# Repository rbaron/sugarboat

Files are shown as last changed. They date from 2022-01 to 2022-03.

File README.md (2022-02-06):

<p align="center" style="background-color: white; padding: 10px">
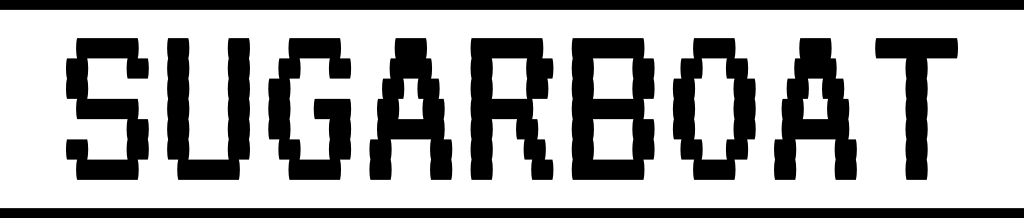
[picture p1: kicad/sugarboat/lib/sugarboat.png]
sugarboat logo
	
<p>

A digital [hydrometer](https://en.wikipedia.org/wiki/Hydrometer). The main use case is measuring the amount of sugar in liquids during the process of beer and wine making.

# How does it work?
Sugarboat floats on top of the liquid being measured. Because of its shifted center of mass, it will float at an angle. This *tilt angle* (see image below) is larger for denser liquids and smaller for less dense liquids. We can then estimate the density of a solution from this angle.

<p align="center">
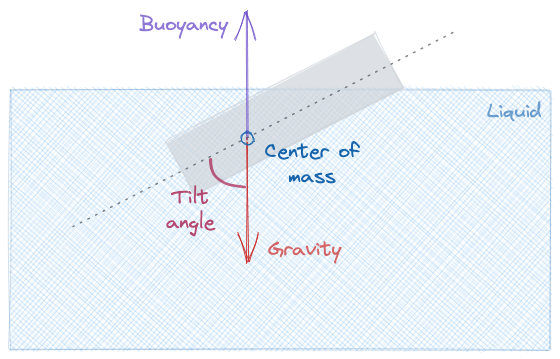
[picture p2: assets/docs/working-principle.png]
	
<p>

As is usual in the beer and wine making processes, we can additionally correlate the estimated density of a solution with the amount of sugar present in it.

The estimated [density](https://en.wikipedia.org/wiki/Relative_density) and [sugar content](https://en.wikipedia.org/wiki/Brix) are exposed - along with the temperature, relative humidity, current battery voltage and more - through [Bluetooth Low Energy (BLE)](https://en.wikipedia.org/wiki/Bluetooth_Low_Energy) services. This repository contains examples of how to read these values under [`clients/`](./clients).

# Tech specs
* [nRF52840](https://www.nordicsemi.com/Products/nRF52840) system-on-a-chip
  * Reads sensors, estimates the sugar content and exposes their values via [Bluetooth Low Energy (BLE)](https://en.wikipedia.org/wiki/Bluetooth_Low_Energy) services
* [SHT30](https://www.mouser.com/datasheet/2/682/Sensirion_Humidity_Sensors_SHT3x_Datasheet_digital-971521.pdf) temperature & humidity sensor
* [MPU6050](https://invensense.tdk.com/products/motion-tracking/6-axis/mpu-6050/) accelerometer + gyroscope estimates the tilt angle
* Li-Ion 18650 battery
  * Battery life of over a year on a single charge
  * Built-in [TP4056](http://www.tp4056.com/d/tp4056.pdf)-based charging circuit
* USB-C for battery charging and programming
  * [UF2 support](https://learn.adafruit.com/adafruit-feather-m0-express-designed-for-circuit-python-circuitpython/uf2-bootloader-details) using a [forked Adafruit_nRF52_Bootloader](https://github.com/rbaron/Adafruit_nRF52_Bootloader) allows for direct programming via the USB-C port. This bootloader needs to be flashed to the blank nRF52 chip once using a J-Link or compatible SWD programmer

# Waterproof enclosure
A [preform PET tube (or "petling")](https://en.wikipedia.org/wiki/Polyethylene_terephthalate#Bottle_processing_equipment) is used to enclose the electronics and provide sugarboat with the buoyancy it needs. The printed circuit board is designed to fit tightly into a tube with the inner diameter of around 33 mm and inner height of 123 mm. The board is slightly wider than 33 mm - some light sanding needs to be done to ensure a nice, snuggly fit. I bought my containers from [this eBay offering](https://www.ebay.com/itm/132379354446).

# Repository organization
| Directory | Description |
|---|---|
| [`kicad/`](./kicad) | Electronics - schematic, PCB layout, bill of materials and fabrication files |
| [`code/`](./code) | Firmware - a [PlatformIO](https://platformio.org/) project using the Arduino framework |
| [`clients/web/`](./clients/web) | A web interface for calibrating, configuring and reading sugarboat's sensors |
| [`clients/arduino/`](./clients/arduino) | A barebones Arduino sketch showing how to read sugarboat's tilt angle, temperature & battery voltage using a Bluetooth Low Energy client |
| [`clients/esphome/`](./clients/esphome) | An [ESPHome](https://esphome.io/) client that integrates with [Home Assistant](https://www.home-assistant.io/) |

# Web client
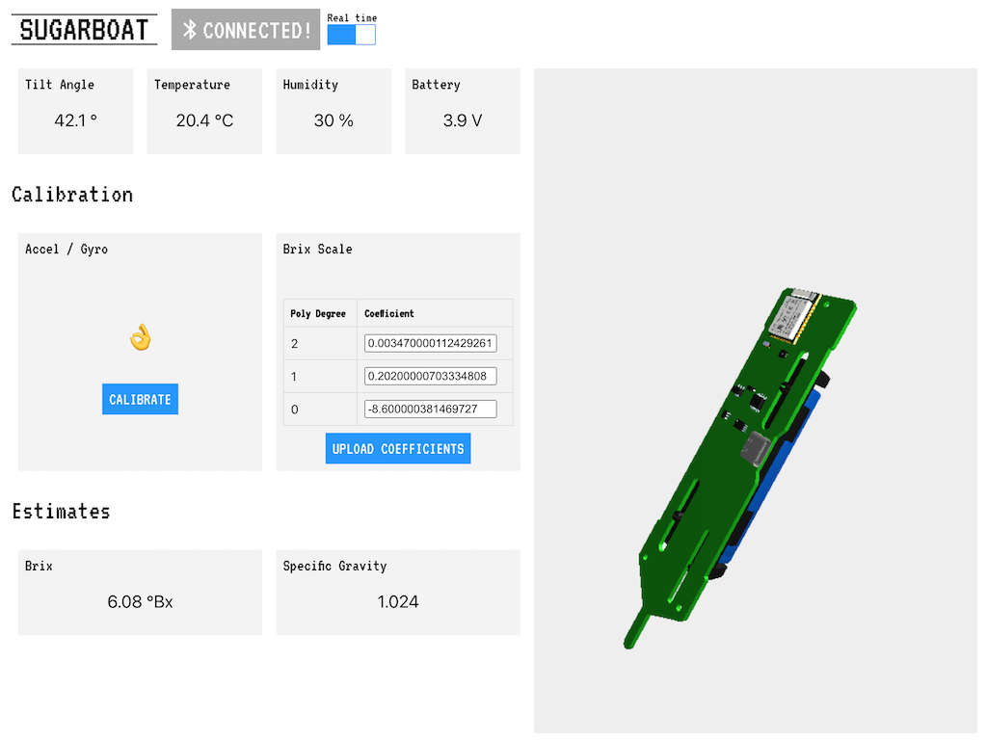
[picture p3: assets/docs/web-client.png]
web client screenshot

This client is a web page that connects to sugarboat using the [Web Bluetooth API](https://developer.mozilla.org/en-US/docs/Web/API/Web_Bluetooth_API). It lets you calibrate, configure and read the sensor values right from your web browser, wirelessly.

The web client's source code is in [`clients/web/`](./clients/web).

# Calibration
TODO.

# Bootloader flashing
To support programming via the built-in USB-C port (via [UF2](https://github.com/microsoft/uf2)), sugarboat requires a bootloader to be flashed to the chip. This is a one-time operation.

I have [forked the Adafruit nRF52 Bootloader](https://github.com/rbaron/Adafruit_nRF52_Bootloader) and added support to sugarboat. To build and flash the bootloader:

```bash
$ git clone git@github.com:rbaron/Adafruit_nRF52_Bootloader.git
$ cd Adafruit_nRF52_Bootloader/
$ make BOARD=sugarboat all
$ make BOARD=sugarboat erase
# Look for the build target that contains the merged bootloader + Nordic's SoftDevice and flash it.
# It will be something like _build/build-sugarboat/sugarboat_bootloader-X.X.X-XXX-XXXXXXXXX_s140_6.1.1.hex:
$ nrfjprog --program _build/build-sugarboat/sugarboat_bootloader-0.4.0-149-g5ffac2e_s140_6.1.1.hex -f nrf52 --reset
```

Note that you will need a SWD programmer to complete this operation. A good choice for hobbyists is a [J-Link EDU Mini](https://www.adafruit.com/product/3571). If you buy one, consider getting it from Adafruit.

# License
[CC BY-NC-ND 4.0](https://creativecommons.org/licenses/by-nc-nd/4.0/).

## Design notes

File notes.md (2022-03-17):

# MPU-6050
* [Datasheet](https://invensense.tdk.com/wp-content/uploads/2015/02/MPU-6000-Datasheet1.pdf)
* [Register map](https://invensense.tdk.com/wp-content/uploads/2015/02/MPU-6000-Register-Map1.pdf)
* It's a 6 degrees of freedom IMU
  * Accelerometer with 3 axes => Reads
  * Gyroscope with 3 axes
* But also has a built-in "MotionFusion" Digital Motion Processor (DMP)
  * "Offloads computation of motion processing algorithms" from the host processor (?)
  * Generates "sensor fusion data" (?)
  * So it becomes a 9-axis sensor
  * Somehow lets us extract the orientation from the accelerometer + gyro
  * Apparently [not publicly documented](https://github.com/jrowberg/i2cdevlib/blob/master/Arduino/MPU6050/MPU6050.h#L731)
  * [This GitHub comment](https://github.com/jrowberg/i2cdevlib/issues/528#issuecomment-611634501) links to a PDF containing the specs of the firmware that powers the DMP
  * [Clear explanation of the DMP](https://github.com/jrowberg/i2cdevlib/issues/190#issuecomment-144270345) by the author of i2cdevlibA
  * [Motion determination patent](https://patents.google.com/patent/US20120323520A1/en)

## Articles
* [Geek Mom Projects - DMP data from i2cdevlib](http://www.geekmomprojects.com/mpu-6050-dmp-data-from-i2cdevlib/)
* [The MPU6050 Explained](https://mjwhite8119.github.io/Robots/mpu6050)
  * Awesome resource for calibrating and getting the orientation using the DMP feature. It uses the i2cdevlib linked below

## Code
* [i2cdevlib](https://github.com/jrowberg/i2cdevlib)
  * [Code for reading the DMP](https://github.com/jrowberg/i2cdevlib/blob/master/Arduino/MPU6050/MPU6050_6Axis_MotionApps20.cpp#L118)
    * Apparently makes use of undocumented functionality!
    * There are multiple versions of the
  * [examples/MPU6050-DMP6](https://github.com/jrowberg/i2cdevlib/tree/master/Arduino/MPU6050/examples/MPU6050_DMP6)
    * Computes orientation using the DMP feature
  * [examples/IMU_Zero](https://github.com/jrowberg/i2cdevlib/tree/master/Arduino/MPU6050/examples/IMU_Zero)
    * Calibrates the gyroscope and accelerometer offsets
  * [Issues with PlatoformIO](https://community.platformio.org/t/i2cdev-incompatible-with-teensy-i2c-t3/11537/4)
* [MPU6050_light](https://github.com/rfetick/MPU6050_light)
  * A library for the MPU-6050 that estimates the angles in software (no DMP?)
* [MPU605-tockn](https://github.com/tockn/MPU6050_tockn)
  * Also calculates angles in software

 ## Calibration
 ```
 [-1743,-1742] --> [-7,11]  [719,720] --> [-7,5]    [1101,1101] --> [16381,16386]   [100,101] --> [0,3]     [60,61] --> [0,4]       [1,1] --> [0,1]

 [-1743,-1742]
 [719,720]
 [1101,1101]
 [100,101]
 [60,61]
 [1,1]
 ```

 ## How to calculate the tilt?
 Tilt: the angle between the sensor and the original's frame Z axis (or equivalently the gravity)

 The sensor gives us a quaternion.

### Euler angles
* [Converting quaternions to Euler angles](https://en.wikipedia.org/wiki/Conversion_between_quaternions_and_Euler_angles)
*

### Row pitch yaw

## Alternative approach
* [Inclination sensing with accelerometer](https://www.digikey.com/en/articles/using-an-accelerometer-for-inclination-sensing) article from DigiKey
* [LIS2DW](https://www.st.com/resource/en/datasheet/lis2dw.pdf) ultra low power accelerometer

# Container
* [Centrifuge tube](https://www.thermofisher.com/order/catalog/product/339650)
* [Falcon tube](https://www.fishersci.com/shop/products/falcon-50ml-conical-centrifuge-tubes-2/p-193321)

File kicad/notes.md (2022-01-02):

# Battery Protection
* [DW01a](https://datasheet.lcsc.com/lcsc/1912111437_PUOLOP-DW01A_C351410.pdf) requires two external N-channel MOSFETs
  * [2n7002dw](https://datasheet.lcsc.com/lcsc/2008111605_Yangzhou-Yangjie-Elec-Tech-2N7002DW_C699281.pdf)
  * [fs8205a](https://datasheet.lcsc.com/lcsc/2105241639_TECH-PUBLIC-FS8205A_C2830320.pdf)
    * Two drains are connected

* Reverse polarity protection
  * How would it work when the battery has to charge & also discharge at different times?

# LDO
* [ap2112](https://www.diodes.com/assets/Datasheets/AP2112.pdf)
  * 600 mA
  * 55 uA quiescent current
* [ht7733a](https://www.electroschematics.com/wp-content/uploads/2013/05/ht7750a-ht7727a-ht7730a-ht7733a-datasheet.pdf)
  *
* [ht7333](https://www.endrich.com/fm/2/HT73xx-1v100.pdf)
  * 250 mA
  * 2.5 uA quiescent current

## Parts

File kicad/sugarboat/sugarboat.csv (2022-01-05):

Comment | Designator | Footprint | LCSC
Battery_Cell | BT1 | lib:BAT_1042_modified
0.1u | C1,C10,C11 | Capacitor_SMD:C_0402_1005Metric | C1525
2.2n | C12 | Capacitor_SMD:C_0402_1005Metric | C1531
10u | C2,C3,C4,C5 | Capacitor_SMD:C_0402_1005Metric | C15525
12p | C6,C7 | Capacitor_SMD:C_0402_1005Metric | C1547
100n | C8 | Capacitor_SMD:C_0402_1005Metric | C1525
10n | C9 | Capacitor_SMD:C_0402_1005Metric | C15195
GREEN | D1 | LED_SMD:LED_0402_1005Metric | C409787
RED | D2,D4 | LED_SMD:LED_0402_1005Metric | C130719
B5819W SL | D3 | SOD3716X135N | C8598
DW01A | IC1 | SOT23-6 | C351410
TYPE-C-31-M-12 | J1 | HRO_TYPE-C-31-M-12 | C165948
FS8205A | Q1 | SOP65P640X120-8N
AO3401A | Q2 | Package_TO_SOT_SMD:SOT-23 | C332107
100 | R1 | Resistor_SMD:R_0402_1005Metric | C25076
1k | R2,R4,R5,R11 | Resistor_SMD:R_0402_1005Metric | C11702
2k | R3 | Resistor_SMD:R_0402_1005Metric | C4109
10k | R6,R12,R13 | Resistor_SMD:R_0402_1005Metric | C25744
470k | R7,R8 | Resistor_SMD:R_0402_1005Metric | C25790
5.1k | R9,R10 | Resistor_SMD:R_0402_1005Metric | C25905
TestPoint | TP1,TP2,TP3,TP4,TP5 | TestPoint:TestPoint_Pad_D1.5mm
TP4056 | U1 | SOP127P600X175-9N | C382139
MPU-6050 | U2 | Sensor_Motion:InvenSense_QFN-24_4x4mm_P0.5mm | C24112
HT7330 | U3 | lib:SOT89 | C347190
E73-2G4M08S1C | U4 | lib:E73-2G4M08S1C-modified | C356849
SHT30-DIS | U5 | Sensor_Humidity:Sensirion_DFN-8-1EP_2.5x2.5mm_P0.5mm_EP1.1x1.7mm | C2687423
32.768 kHz | Y1 | XTAL_NX3215SA-32.768K-STD-MUA-14 | C32346

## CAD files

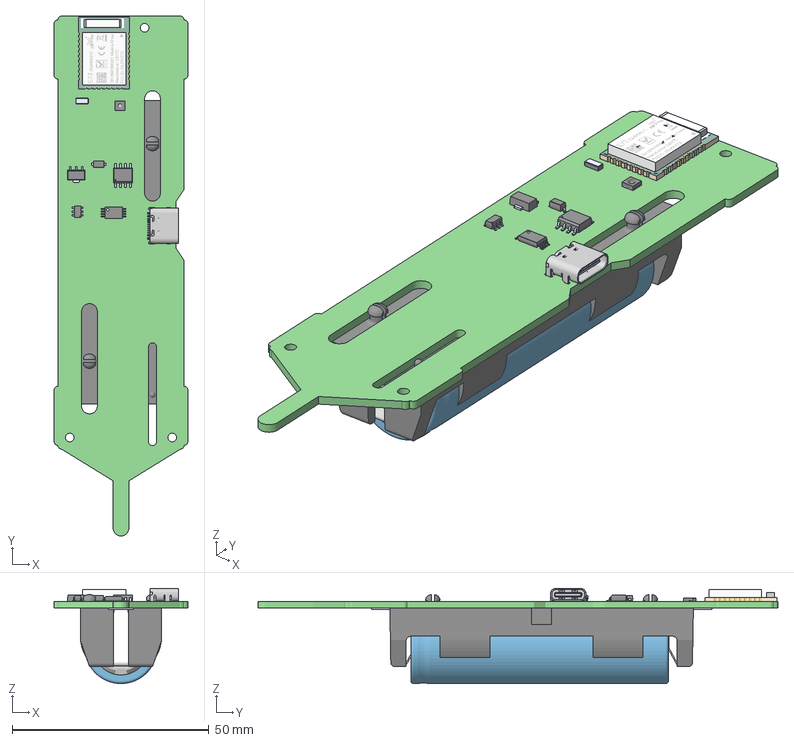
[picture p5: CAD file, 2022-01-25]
clients/web/public/sugarboat.3mf
34.0 x 132.0 x 24.2 mm

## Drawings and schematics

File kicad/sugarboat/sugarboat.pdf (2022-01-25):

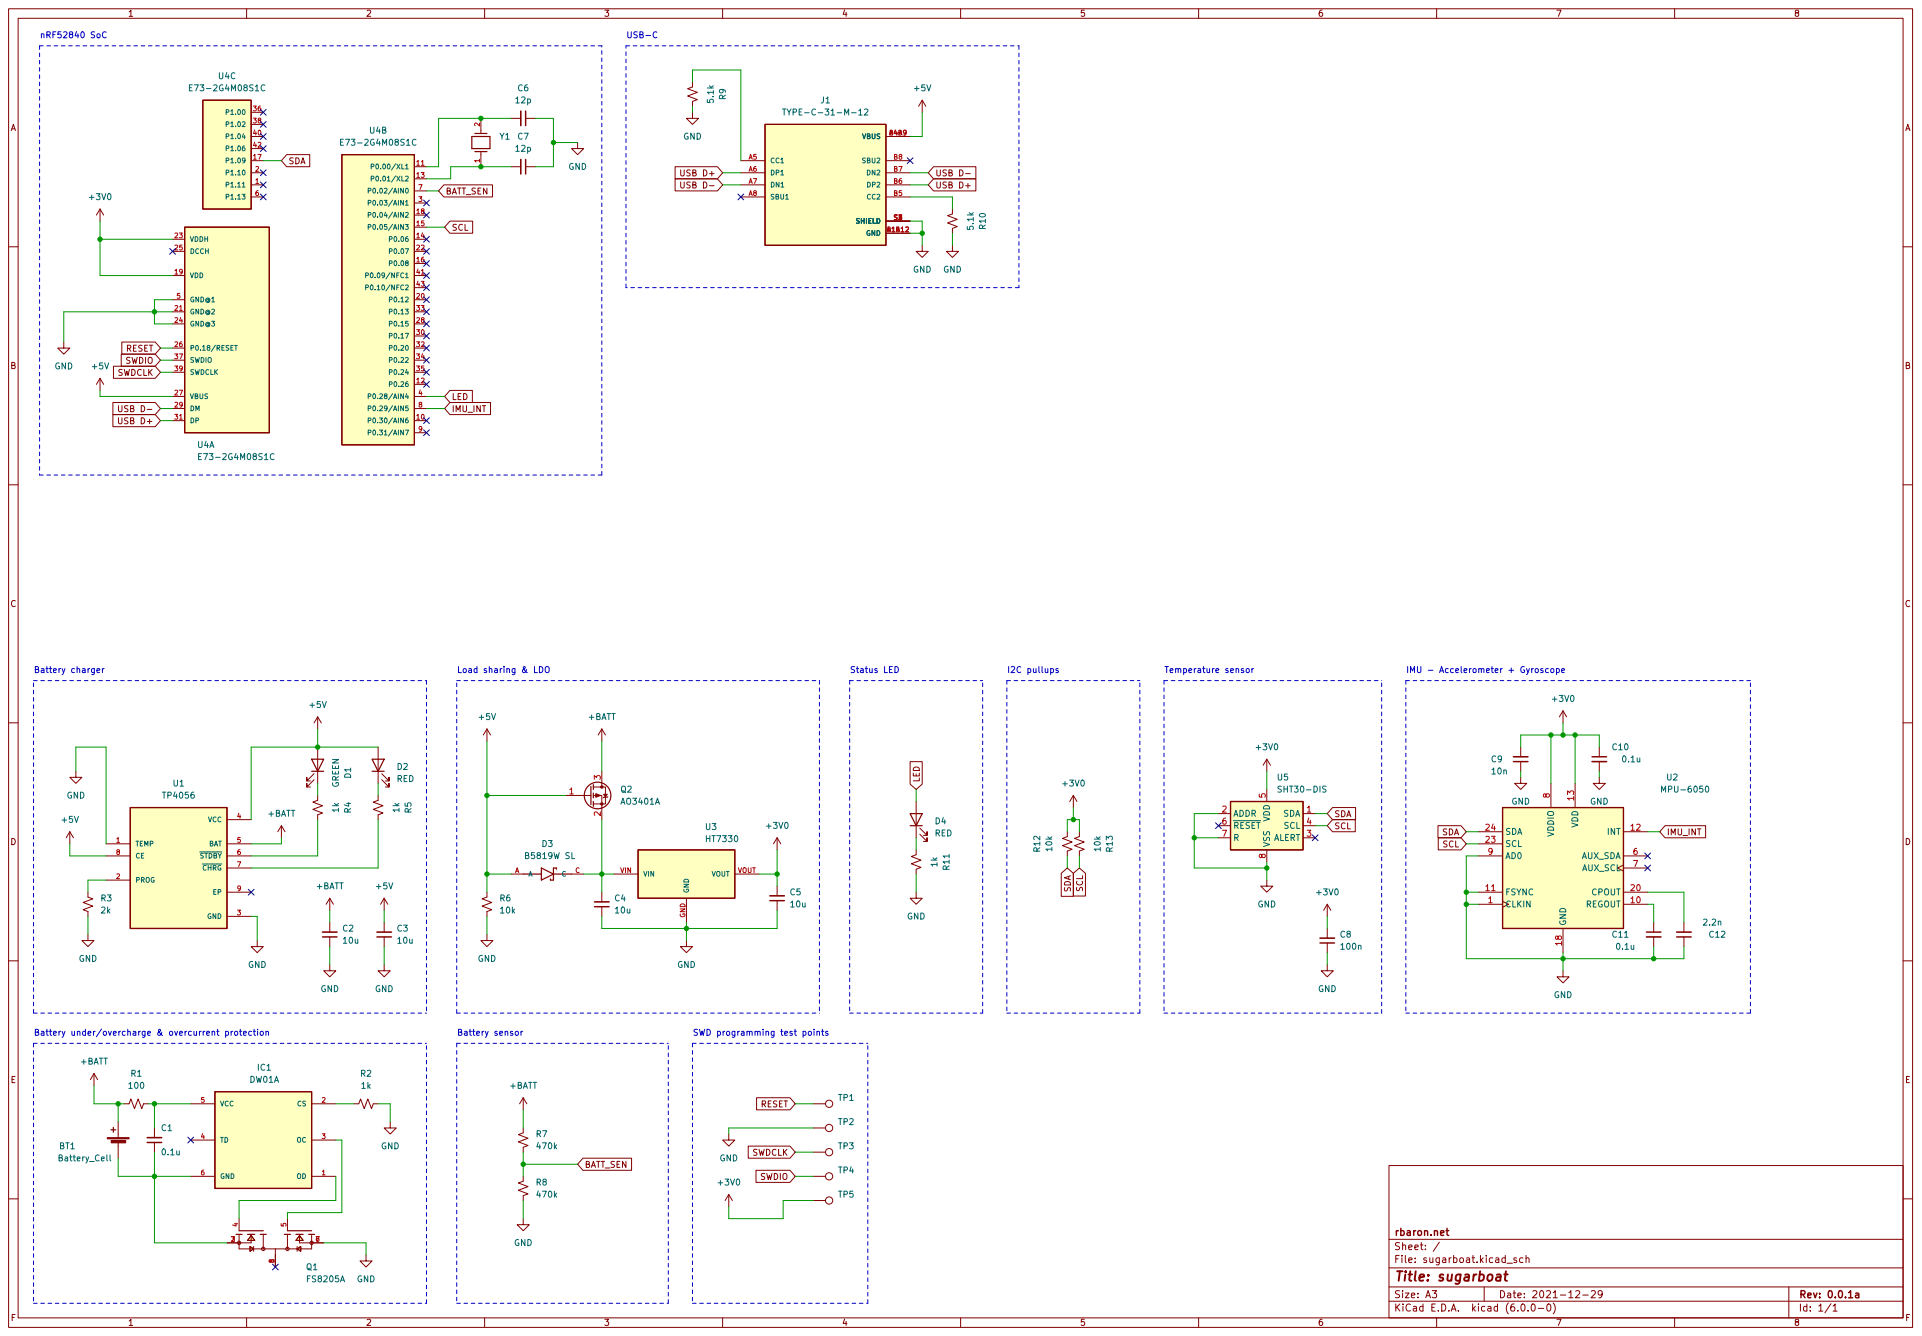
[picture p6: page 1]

Battery under/overcharge & overcurrent protection

SWD programming test points

File: sugarboat.kicad_sch Sheet: / rbaron.net

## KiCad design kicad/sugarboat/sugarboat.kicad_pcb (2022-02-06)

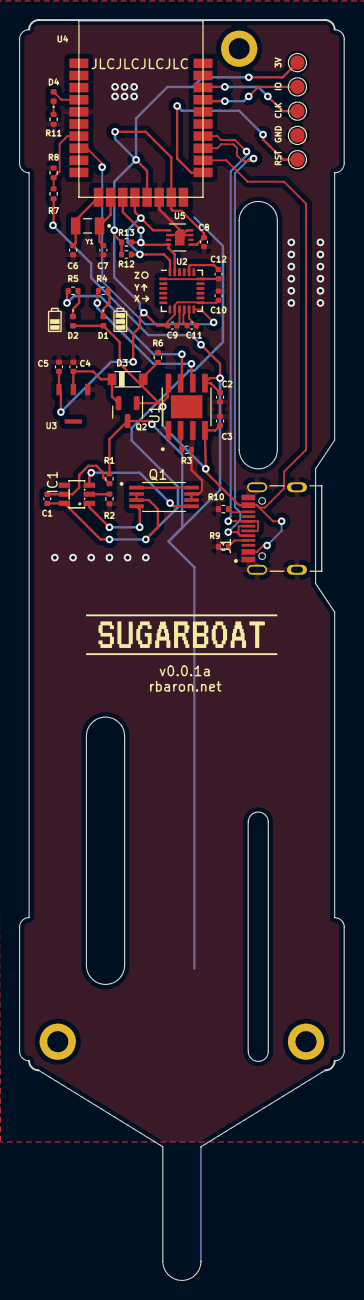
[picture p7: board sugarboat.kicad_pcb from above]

Board: 2 copper layers, 34.0 x 132.0 mm, 45 parts (1 on the bottom side), 32 nets.

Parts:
BT1: Battery_Cell; BAT_1042_modified
C1, C10, C11: 0.1u; C_0402_1005Metric
C2, C3, C4, C5: 10u; C_0402_1005Metric
C6, C7: 12p; C_0402_1005Metric
C8: 100n; C_0402_1005Metric
C9: 10n; C_0402_1005Metric
C12: 2.2n; C_0402_1005Metric
D1: GREEN; LED_0402_1005Metric
D2, D4: RED; LED_0402_1005Metric
D3: B5819W SL; SOD3716X135N
IC1: DW01A; SOT23-6
J1: TYPE-C-31-M-12; HRO_TYPE-C-31-M-12
Q1: FS8205A; SOP65P640X120-8N
Q2: AO3401A; SOT-23
R1: 100; R_0402_1005Metric
R2, R4, R5, R11: 1k; R_0402_1005Metric
R3: 2k; R_0402_1005Metric
R6, R12, R13: 10k; R_0402_1005Metric
R7, R8: 470k; R_0402_1005Metric
R9, R10: 5.1k; R_0402_1005Metric
TP1, TP2, TP3, TP4, TP5: TestPoint; TestPoint_Pad_D1.5mm
U1: TP4056; SOP127P600X175-9N
U2: MPU-6050; InvenSense_QFN-24_4x4mm_P0.5mm
U3: HT7330; SOT89
U4: E73-2G4M08S1C; E73-2G4M08S1C-modified
U5: SHT30-DIS; Sensirion_DFN-8-1EP_2.5x2.5mm_P0.5mm_EP1.1x1.7mm
Y1: 32.768 kHz; XTAL_NX3215SA-32.768K-STD-MUA-14

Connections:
+3V0: C5.2, C8.2, C9.2, C10.1, R12.2, R13.1, TP5.1, U2.8 (VDDIO), U2.13 (VDD), U3.VOUT, U4.19 (VDD), U4.23 (VDDH), U5.5 (VDD)
+5V: C3.2, D1.2 (A), D2.2 (A), D3.A, J1.A4B9 (VBUS), J1.B4A9 (VBUS), Q2.1 (G), R6.1, U1.4 (VCC), U1.8 (CE), U4.27 (VBUS)
+BATT: BT1.+, C2.2, Q2.3 (D), R1.1, R7.1, U1.5 (BAT)
BATT_SEN: R7.2, R8.1, U4.7 (P0.02/AIN0)
GND: C2.1, C3.1, C4.1, C5.1, C6.1, C7.1, C8.1, C9.1, C10.2, C11.2, C12.1, J1.A1B12 (GND), J1.B1A12 (GND), J1.S1 (SHIELD), J1.S2 (SHIELD), J1.S3 (SHIELD), J1.S4 (SHIELD), Q1.6, Q1.7, R2.2, R3.2, R6.2, R8.2, R9.2, R10.2, R11.2, TP2.1, U1.1 (TEMP), U1.3 (GND), U2.1 (CLKIN), U2.9 (AD0), U2.11 (FSYNC), U2.18 (GND), U3.GND, U4.5 (GND@1), U4.21 (GND@2), U5.2 (ADDR), U5.7 (R), U5.8 (VSS), U5.9 (VSS)
IMU_INT: U2.12 (INT), U4.8 (P0.29/AIN5)
LED: D4.2 (A), U4.4 (P0.28/AIN4)
unnamed: BT1.-, C1.1, IC1.6 (GND), Q1.2, Q1.3
unnamed: C1.2, IC1.5 (VCC), R1.2
unnamed: C4.2, D3.C, Q2.2 (S), U3.VIN
unnamed: C6.2, U4.11 (P0.00/XL1), Y1.2
unnamed: C7.2, U4.13 (P0.01/XL2), Y1.1
unnamed: C11.1, U2.10 (REGOUT)
unnamed: C12.2, U2.20 (CPOUT)
unnamed: D1.1 (K), R4.1
unnamed: D2.1 (K), R5.1
unnamed: D4.1 (K), R11.1
unnamed: IC1.1 (OD), Q1.4
unnamed: IC1.2 (CS), R2.1
unnamed: IC1.3 (OC), Q1.5
unnamed: J1.A5 (CC1), R9.1
unnamed: J1.B5 (CC2), R10.1
unnamed: R3.1, U1.2 (PROG)
unnamed: R4.2, U1.6 (~STDBY)
unnamed: R5.2, U1.7 (~CHRG)
RESET: TP1.1, U4.26 (P0.18/RESET)
SCL: R13.2, U2.23 (SCL), U4.15 (P0.05/AIN3), U5.4 (SCL)
SDA: R12.1, U2.24 (SDA), U4.17 (P1.09), U5.1 (SDA)
SWDCLK: TP3.1, U4.39 (SWDCLK)
SWDIO: TP4.1, U4.37 (SWDIO)
USB D+: J1.A6 (DP1), J1.B6 (DP2), U4.31 (DP)
USB D-: J1.A7 (DN1), J1.B7 (DN2), U4.29 (DM)

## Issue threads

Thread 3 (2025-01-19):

Suport for Programing

azgael, 2025-01-19:
Dear Rbaron
I have built  and soldered the sugarboat and would like to bring it to life, I have program the bootloader but not sure if is flashed the firmware.
would it be possible to have from you some orientation in how to flash, configure  and read data from it, I would like to use it with homeassistant.
Thank you very much in advance!!!
BR
Azgael

rbaron, 2025-01-21:
@azgael,

The programming is done with the standard SWD Arm interface. There's [a wiki page on a similar project](https://github.com/rbaron/b-parasite/wiki/How-to-Flash-the-Firmware-Samples) that I hope is a good starting point. The programming connections are exactly the same. Other pages on that same wiki might also be interesting.

In the [README there's a link](https://github.com/rbaron/sugarboat?tab=readme-ov-file#repository-organization) to some of the clients I wrote a couple of years ago when I was actively working on Sugarboat. One of them is an ESPHome (and Home Assistant) integration (see [clients/esphome/sugarboat-bridge.yaml)](https://github.com/rbaron/sugarboat/blob/main/clients/esphome/sugarboat-bridge.yaml)). I have a different setup and I haven't used it since, so you may need to do some adjustments for newer ESPHome versions.

Good luck!

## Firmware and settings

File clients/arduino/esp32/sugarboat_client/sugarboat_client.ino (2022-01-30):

#include "BLEDevice.h"
#include <memory>

static constexpr char kSugarboatMACAddr[] = "dc:a6:64:68:ef:5f";
static  BLEUUID kServiceUUID("9b7d5c6f-a8ca-4080-9290-d4afb5ac64a3");
static  BLEUUID    kCharUUID("527d0f9b-db66-48c5-9089-071e1a795b6f");

static boolean doConnect = false;
static boolean connected = false;
static BLERemoteCharacteristic* pRemoteCharacteristic;
//static BLEAdvertisedDevice* myDevice;
static std::unique_ptr<BLEAdvertisedDevice> myDevice;

template<typename Type>
Type parse_bytes(uint8_t *buf, uint16_t idx) {
  Type ret;
  memcpy(&ret, buf + idx, sizeof(Type));
  return ret;
}

static void handleSugarboatSensorData(uint8_t *data, size_t len) {
    if (len < 14) {
    Serial.printf("[ble][handleSugarboatSensorData] Not enough data was received: %d bytes\n", len);
    return;
  }
  float tilt_angle = parse_bytes<int16_t>(data, 2) / 10.0f;
  float brix = parse_bytes<int16_t>(data, 4) / 100.0f;
  float specific_gravity = parse_bytes<int16_t>(data, 6) / 1000.0f;
  float temp_celcius = parse_bytes<int16_t>(data, 8) / 100.0f;
  float rel_humidity = 100.0 * parse_bytes<uint16_t>(data, 10) / ((float) UINT16_MAX);
  float batt_voltage = parse_bytes<uint16_t>(data, 12) / 1000.0f;
  
  Serial.printf("[ble][handleSugarboatSensorData] Tilt angle: %.2f °, Brix: %.2f °Bx, SG: %.2f, Temp: %.2f °C, Humi: %.2f %, Batt: %.2f V\n",
    tilt_angle,
    brix,
    specific_gravity,
    temp_celcius,
    rel_humidity,
    batt_voltage);
}

static void startScanning() {
  BLEDevice::getScan()->start(5, scanCompleteCB, false);
}

static void notifyCallback(
  BLERemoteCharacteristic* pBLERemoteCharacteristic,
  uint8_t* pData,
  size_t length,
  bool isNotify) {
  return handleSugarboatSensorData(pData, length);
}


void scanCompleteCB(BLEScanResults results) {
  Serial.println("[ble] Scan complete. Restarting scan.");
  startScanning();
}

class MyClientCallback : public BLEClientCallbacks {
  void onConnect(BLEClient* pclient) {
    Serial.println("[ble] Connected!");
    connected = true;
  }

  void onDisconnect(BLEClient* pclient) {
    Serial.println("[ble] Disconnected. Will resume scanning");
    connected = false;
    startScanning();
  }
};

static MyClientCallback client_callbacks;

bool connectToServer() {
    if (connected) {
      Serial.println("[ble] Already connected - skipping new connection");
      return true;
    }
    
    Serial.printf("[ble] Connecting to %s\n", myDevice->getAddress().toString().c_str());
    
    BLEClient*  pClient  = BLEDevice::createClient();
    pClient->setClientCallbacks(&client_callbacks);
    pClient->connect(myDevice.get());
    Serial.println("[ble] Connected to sugarboat");

    BLERemoteService* pRemoteService = pClient->getService(kServiceUUID);
    if (pRemoteService == nullptr) {
      Serial.print("[ble] Failed to find our service UUID. Disconnecting.");
      pClient->disconnect();
      return false;
    }
    Serial.println("[ble] Service found");

    pRemoteCharacteristic = pRemoteService->getCharacteristic(kCharUUID);
    if (pRemoteCharacteristic == nullptr) {
      Serial.printf("[ble] Char %s not found. Disconnecting.\n", kCharUUID.toString().c_str());
      pClient->disconnect();
      return false;
    }
    Serial.println("[ble] Characteristic found");

    if(pRemoteCharacteristic->canRead()) {
      std::string value = pRemoteCharacteristic->readValue();
    }

    if(pRemoteCharacteristic->canNotify()) {
      Serial.println("[ble] Registering for notify events");
      pRemoteCharacteristic->registerForNotify(notifyCallback);
    }
    return true;
}


class MyAdvertisedDeviceCallbacks: public BLEAdvertisedDeviceCallbacks {
  void onResult(BLEAdvertisedDevice advertisedDevice) {
//    Serial.printf("BLE Advertised Device found: %s\n", advertisedDevice.toString().c_str());
    if (advertisedDevice.haveServiceUUID() && advertisedDevice.isAdvertisingService(kServiceUUID)) {
      const std::string found_addr = advertisedDevice.getAddress().toString();
      Serial.printf("[ble] Found a sugarboat @ %s\n", found_addr.c_str());
      if (found_addr != kSugarboatMACAddr) {
        Serial.printf("[ble] This is not the sugarboat we're looking for! Continuing scanning...\n");
        return;
      }
      BLEDevice::getScan()->stop();
//      myDevice = new BLEAdvertisedDevice(advertisedDevice);
      myDevice = std::unique_ptr<BLEAdvertisedDevice>(new BLEAdvertisedDevice(advertisedDevice));
      doConnect = true;
      // TODO: calling connectToServer() directly here causes it to stop execution weirdly. Why?
      // connectToServer();
    }
  }
};

static MyAdvertisedDeviceCallbacks advCallbacks;

void setup() {
  Serial.begin(115200);
  Serial.println("Starting Arduino BLE Client application...");
  BLEDevice::init("");

  BLEScan* pBLEScan = BLEDevice::getScan();
  pBLEScan->setAdvertisedDeviceCallbacks(&advCallbacks);
  pBLEScan->setInterval(1349);
  pBLEScan->setWindow(449);
  pBLEScan->setActiveScan(true);
  startScanning();
}


void loop() {
  if (doConnect == true) {
    if (connectToServer()) {
      Serial.println("[ble] Connected!");
    } else {
      Serial.println("[ble][main] Connection failed. Starting scanning...");
      startScanning();
    }
    doConnect = false;
  }
  
  delay(1000);
}

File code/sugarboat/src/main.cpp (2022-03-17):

#include <Adafruit_LittleFS.h>
#include <Adafruit_TinyUSB.h>
#include <Arduino.h>
#include <bluefruit.h>

#include "Wire.h"
#include "sugarboat/ble.h"
#include "sugarboat/config.h"
#include "sugarboat/mpu6050.h"
#include "sugarboat/sensor_data.h"
#include "sugarboat/sht30.h"

sugarboat::Config config;
sugarboat::BLE &ble = sugarboat::BLE::GetInstance();
sugarboat::IMU imu;
sugarboat::SHT30 sht30;

Adafruit_SHT31 sht31 = Adafruit_SHT31();

#define SGRBT_LED_PIN 16
#define SGRBT_SDA_PIN 6
#define SGRBT_SCL_PIN 10
#define SGRBT_BAT_SEN_PIN 18

// Baseline: 17 uA
// With accel in low power mode: 30 uA
// With BLE + accel lo po: 40 uA

void setup() {
  // Uses ~40uA!
  // pinMode(SGRBT_BAT_SEN_PIN, INPUT);

  pinMode(SGRBT_LED_PIN, OUTPUT);

  digitalWrite(SGRBT_LED_PIN, HIGH);

  Wire.setPins(SGRBT_SDA_PIN, SGRBT_SCL_PIN);
  Wire.begin();
  Wire.setClock(400000);

  Serial.begin(115200);
  // Uncomment to block the execution until the USB serial port is open.
  // while (!Serial)
  //   ;
  delay(500);

  if (!sht30.Init()) {
    Serial.println("[main] Error initializing SHT30");
    while (1) delay(1);
  }

  config = sugarboat::Config::ReadFromFlash();

  sugarboat::IMU::Offsets offsets = config.GetIMUOffsets();
  Serial.printf("[main] IMU offsets from flash: %d %d %d %d %d %d\n",
                offsets.accel_x, offsets.accel_y, offsets.accel_z,
                offsets.gyro_x, offsets.gyro_y, offsets.gyro_z);

  if (imu.Init(offsets)) {
    Serial.printf("[main] Error initializing imu\n");
    while (true)
      ;
  }

  sugarboat::BLE &ble = sugarboat::BLE::GetInstance();
  if (!ble.Init(config, imu)) {
    Serial.println("[main] Error intializing BLE");
    while (true)
      ;
  }
  delay(100);
  ble.StartAdv();

  digitalWrite(SGRBT_LED_PIN, LOW);
}

sugarboat::SensorData sensor_data{0, 0, 0, 0, 0};
void loop() {
  bool is_realtime = config.GetRealtimeRun();

  imu.WakeUp();
  sensor_data.tilt_degrees = imu.GetTilt();
  sensor_data.mpu_temp_celsius = imu.GetTemp();
  imu.Sleep();

  float batt_v = 2 * 3.6f * analogRead(SGRBT_BAT_SEN_PIN) / 1024.0f;

  sensor_data.batt_volt = batt_v;
  sensor_data.rel_humi = sht30.GetHumi();
  sensor_data.temp_celsius = sht30.GetTemp();
  delay(50);

  if (isnan(sensor_data.rel_humi)) {
    sensor_data.rel_humi = 0;
  }
  if (isnan(sensor_data.temp_celsius)) {
    sensor_data.temp_celsius = 0;
  }

  ble.InjectSensorData(sensor_data);

  // Serial.printf("Angle: %.2f Temp: %.2f, Humi: %.2f Batt: %.2f\n",
  //               sensor_data.tilt_degrees, sensor_data.temp_celsius,
  //               sensor_data.rel_humi, sensor_data.batt_volt);

  if (!is_realtime) {
    Serial.printf("[main] Delaying...\n");
    config.WaitForConfigChangeOrDelay();
  }
}

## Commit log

2021-12-25 Reading sensor with adafruit/Adafruit MPU6050@^2.0.5
2021-12-25 Calibration with i2cdevlib works
2021-12-25 Reading Euler angles sort of works, but calibration seems off
2021-12-26 First stab at calculating the angle between the sensor and the z axis
    Sort of works, except if we rotate itaround the y axis. I would love for
    it to be independent of this rotation.
2022-01-02 Initial KiCad project
    [floaty.kicad_pcb, floaty.kicad_sch]
2022-01-03 First routing
    Sort of works, but can be improved.
    [floaty.kicad_pcb, floaty.kicad_sch]
2022-01-04 Better routing
    [floaty.kicad_pcb, floaty.kicad_sch]
2022-01-04 Small fixes in the PCB layout & artwork
    [floaty.kicad_pcb]
2022-01-04 Added LCSC part numbers to all components
    [floaty.kicad_sch]
2022-01-05 Sent v0.0.0a PCB for fabrication
    [floaty-B_Cu.gbl, floaty-B_Mask.gbs, floaty-B_Paste.gbp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]
2022-01-05 Renamed KiCad project to sugarboat
    [floaty-B_Cu.gbl, floaty-B_Mask.gbs, floaty-B_Paste.gbp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]
2022-01-12 First successful test with the real v0.0.1a board!!
2022-01-13 Temp & batt voltage sensor + BLE work
2022-01-16 Adds Brix & specific gravity (SG) estimates to sensor characteristic
2022-01-19 A first stab in low power mode for the MPU6050
    I'm not super happy with it. The MPU is put to sleep and the DMP is
    disabled. When they are turned on, it seems to take ~5 s for the
    orientation to converge.
    Another possibility is to leave it running and lower the sample rate,
    but I have to do some measurements to understand how power hungry and
    efficient that would be.
2022-01-21 Adds clients/arduino/central_example
    It's a Arduino-based BLE central that connects to the sugarboat and is
    notified whenever new sensor values are published to the sensor BLE
    characteristic.
2022-01-25 Moves web client React project to this repo
    [sugarboat.3mf]
2022-01-30 [clients/arduino/esp32] Barebones ESP32 Arduino client
2022-02-06 Updates license to CC BY-NC-ND 4.0
    [sugarboat.kicad_pcb]
2022-02-23 Implements an alternative, lower power IMU usage pattern
    For normal operation, sugarboat is mostly static, meaning the only
    acceleration is due to gravity. Gyroscope effects should be negligible,
    so we don't need fancy, power-hungy sensor fusion algorithms.
    This commit introduces a quick experiment without using the DMP from the
    MPU5060, and calculating the tilt directly from the accelerations alone.
2022-03-04 A bunch of dirty power-optimization changes
2022-03-05 Clean up mpu6050 code
    Removed all DMP code in favor of much lower power-friendly
    acceleration-only mode. It's a bit noisier, but it's a good tradeoff
    from my tests.
2022-03-05 Uses ArduinoJson for config serialization
2022-03-17 Includes MPU's internal temperature in the BLE payload
2022-08-26 Sets TX power to 8
    Average current in connected state increases from 141 uA to 166 uA.
    Worth it.
